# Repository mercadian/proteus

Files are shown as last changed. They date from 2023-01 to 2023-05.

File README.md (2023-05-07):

# Proteus

This repository contains the resources for creating and working with the Proteus.

*For documentation on setting up and using the Proteus, please see the **Wiki** tab above.*

*For the source code used to build the OS image that the Proteus comes with: please see the [proteus-image](https://github.com/mercadian/proteus-image) repository.*

## Contents

**labels** - contains `lumi` files for the model / serial number label on the bottom of the Proteus and the danger label attached to the power supply cable. Use the [Desktop Supplies editor](https://designer.desktopsupplies.com/?page_id=16&product_base=57&product_cms=127) to work with them, item template 62015.

**models** - contains the STL files used to print the Proteus case components.

**pcbs** - contains complete [KiCAD](https://www.kicad.org/) projects for supplemental PCBs used by the Proteus (for example, the front panel). Use KiCAD v6.0.11+.

**vanity-plate** - contains instructions and a sample for creating an image used to etch the Proteus's front aluminum vanity plate and other samples that have been made available for public consumption by generous customers.

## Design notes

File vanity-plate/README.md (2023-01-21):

# Proteus Vanity Plate

The vanity plate for the Proteus is an aluminum plate that can be laser etched with any image you like.

The plate itself is an 80mm x 30mm x 0.8mm flat sheet of aluminum, anodized black on both sides.
Supported images must be at most 76mm x 26mm because the engraver needs a 2mm margin per edge to etch safely. 

## Image Specifications

To create an image for the vanity plate, use the following rules.

- The image must be one of the following formats:
  - SVG, which must fit 76x26mm at 25px/mm
  - BMP, size 1900x650

- The colors must be **binary** (completely black or completely white only). The laser cannot etch grayscale colors; it's either on or off.
  - Grayscale pixels will be converted to black or white based on which color is closer, so please ensure the image you provide only uses black and white so you know what it will look like when it comes out.

- Use **black** for **unetched** background pixels, which will remain black on the actual plate. Use **white** for **foreground** pixels that will be etched; they will be a silvery-gold color on the actual plate.

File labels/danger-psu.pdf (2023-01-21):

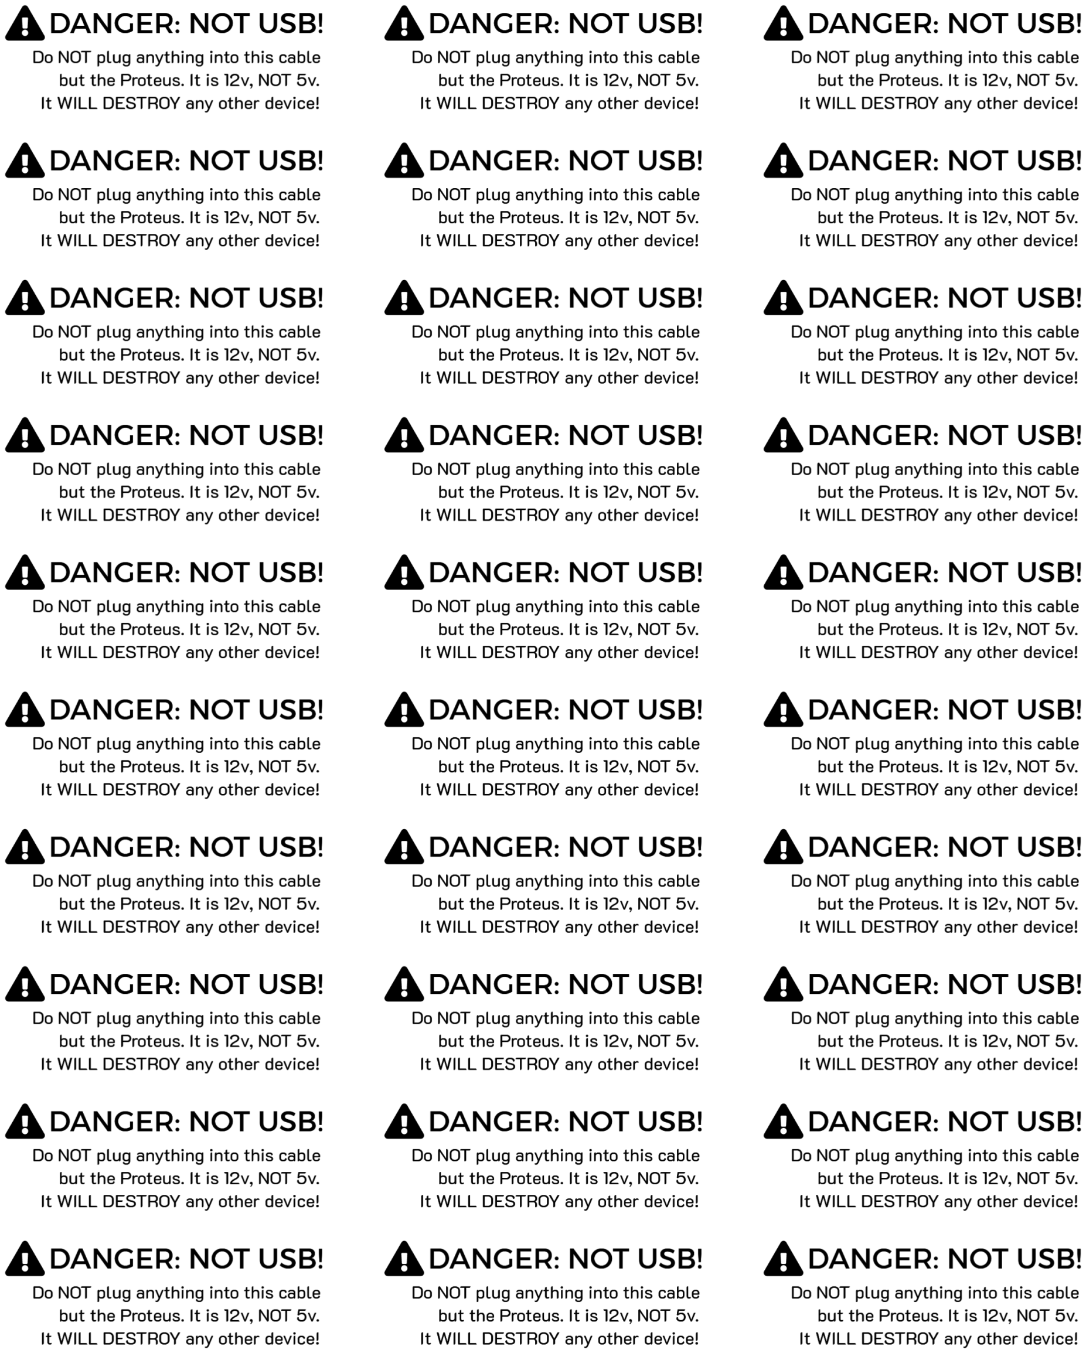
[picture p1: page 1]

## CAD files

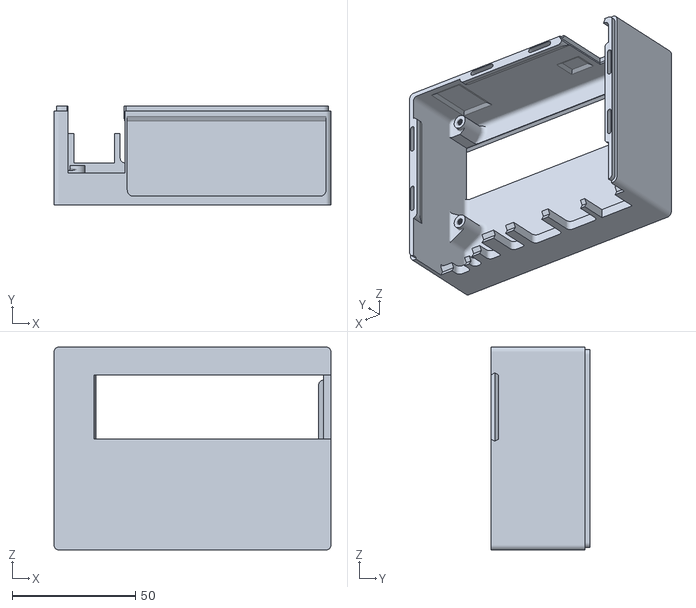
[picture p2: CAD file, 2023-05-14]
models/v1.1/case-bottom.stl
112.2 x 40.0 x 82.2

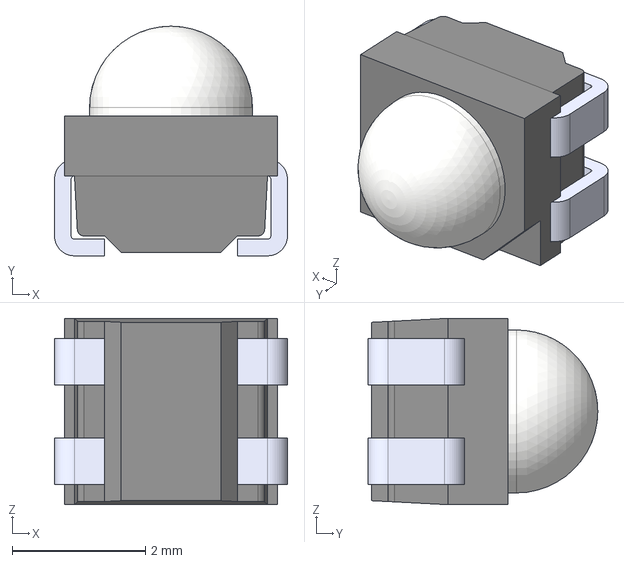
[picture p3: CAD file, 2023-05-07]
pcbs/front-panel/v1.2/models/CLM2D.STEP
3.50 x 3.45 x 2.80 mm

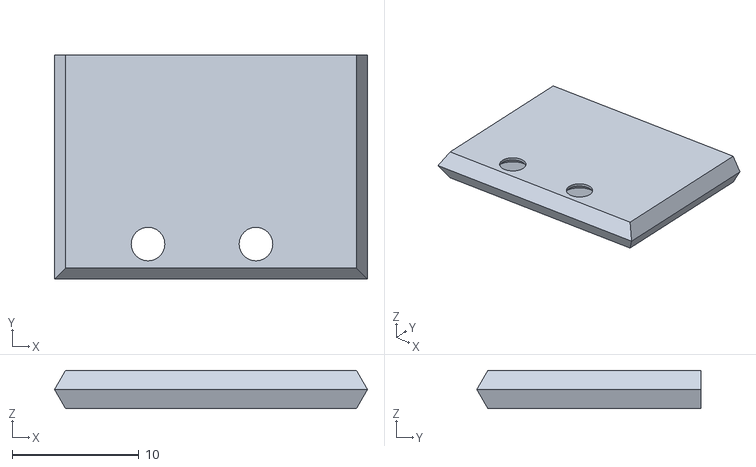
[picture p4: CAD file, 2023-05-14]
models/v1.1/front-panel.stl
24.7 x 17.7 x 3.00

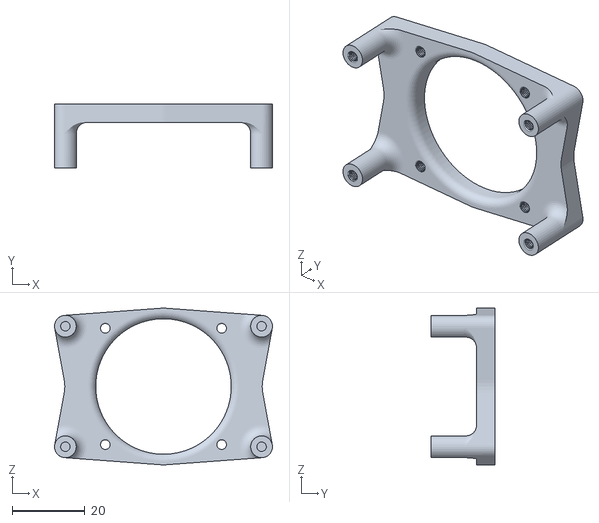
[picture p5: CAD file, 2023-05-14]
models/v1.1/fan-mount.stl
59.9 x 17.5 x 43.1

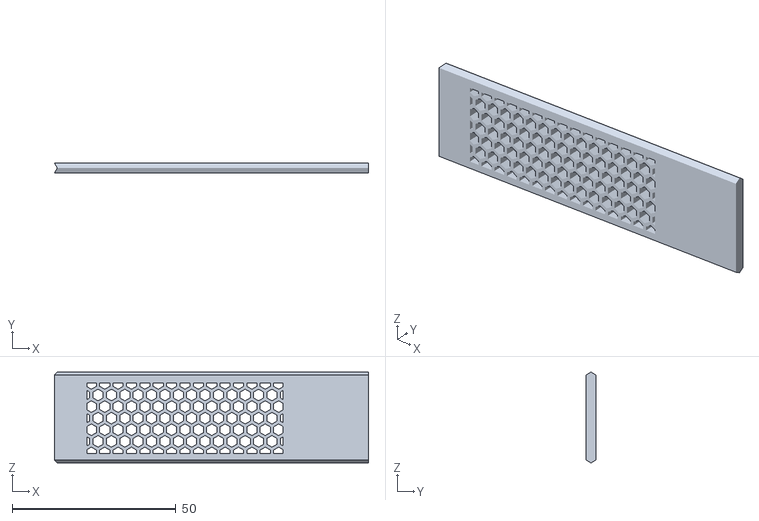
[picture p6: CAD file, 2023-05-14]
models/v1.1/ssd-cover.stl
96.0 x 3.00 x 27.8

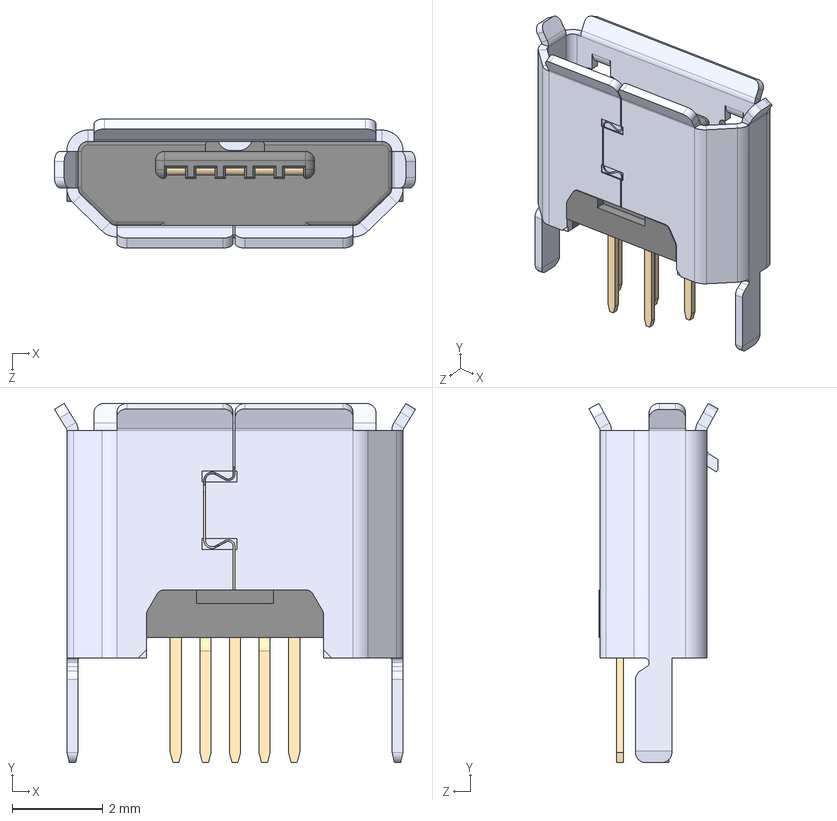
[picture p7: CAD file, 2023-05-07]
pcbs/gpio-board/v1.2/Models/USB3131-30-0230-A_REVB.step
7.94 x 7.90 x 2.84 mm

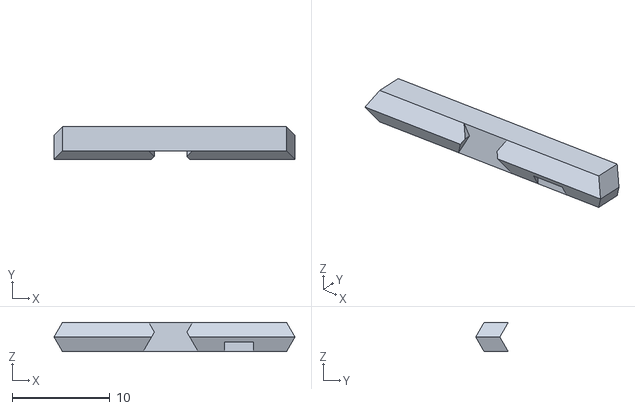
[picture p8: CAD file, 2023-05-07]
models/v1.1/power-button-holder-top.stl
24.7 x 3.34 x 3.00

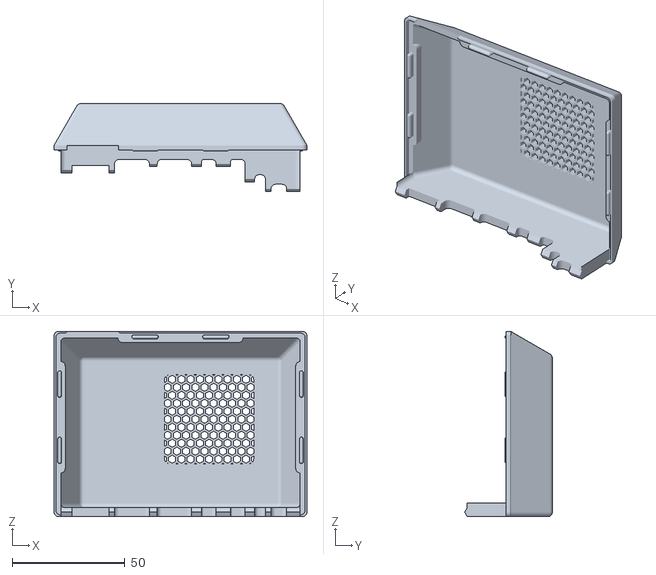
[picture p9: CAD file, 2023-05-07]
models/v1.1/case-top.stl
112.2 x 38.9 x 82.2

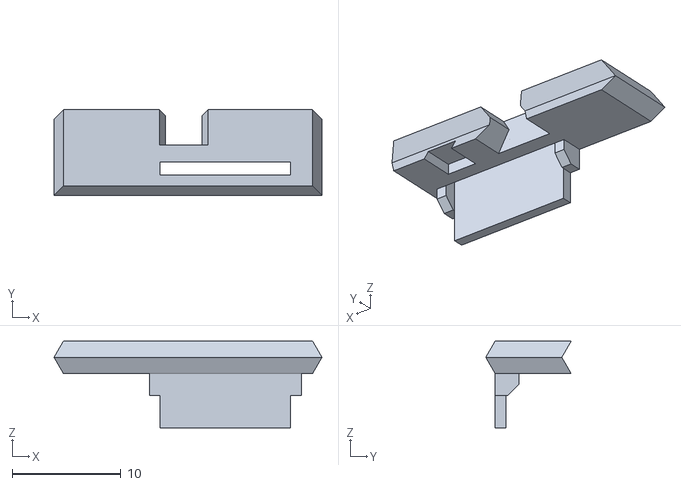
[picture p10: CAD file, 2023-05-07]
models/v1.1/power-button-holder-bottom.stl
24.7 x 7.87 x 8.00

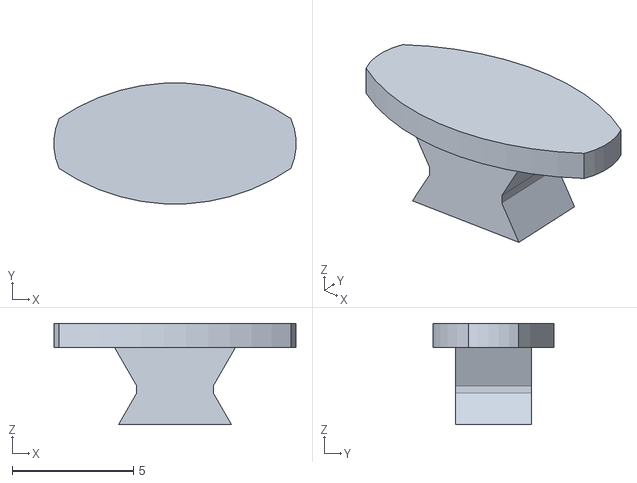
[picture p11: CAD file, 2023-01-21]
models/v1.1/power-button.stl
9.98 x 4.97 x 4.17

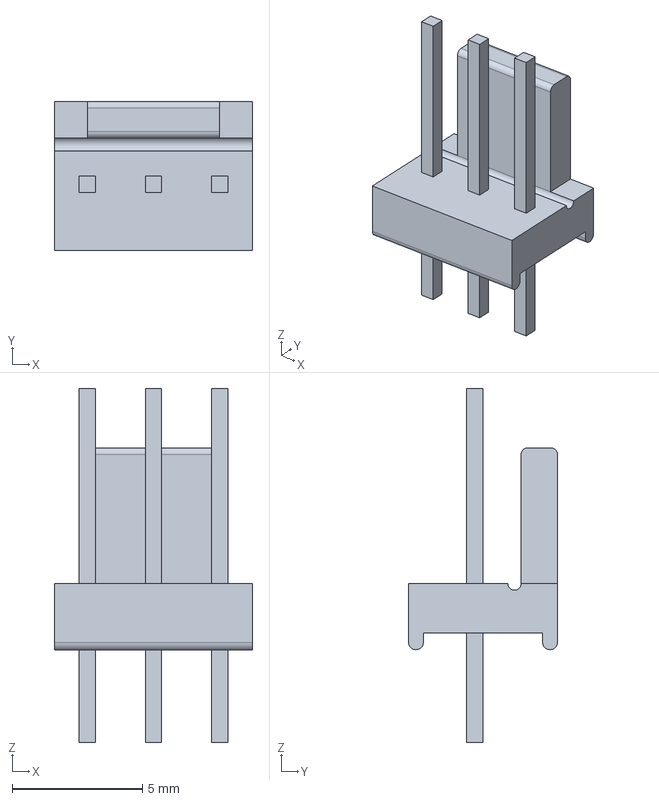
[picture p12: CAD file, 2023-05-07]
pcbs/front-panel/v1.2/step/640454-3.step
7.62 x 5.72 x 13.6 mm

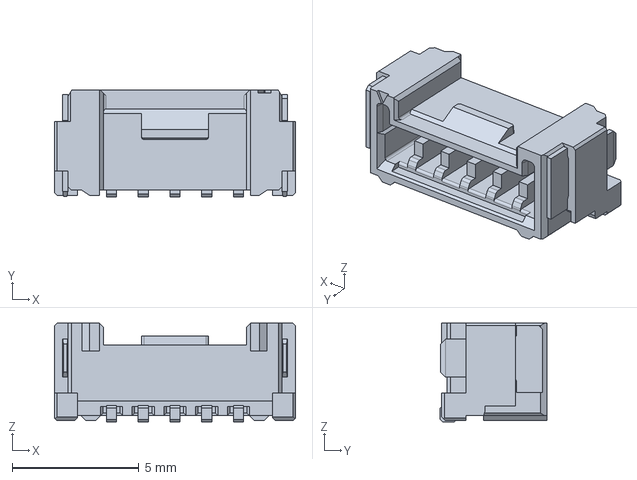
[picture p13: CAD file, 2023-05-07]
pcbs/gpio-board/v1.2/Models/5055680571.step
9.50 x 4.20 x 3.90 mm

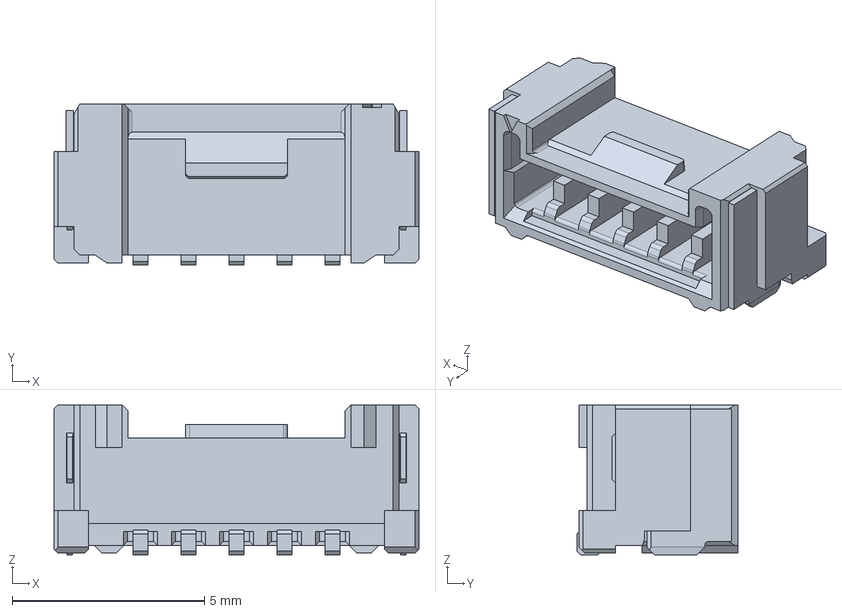
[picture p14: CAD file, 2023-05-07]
pcbs/front-panel/v1.2/models/5055670571.step
9.50 x 4.20 x 3.90 mm

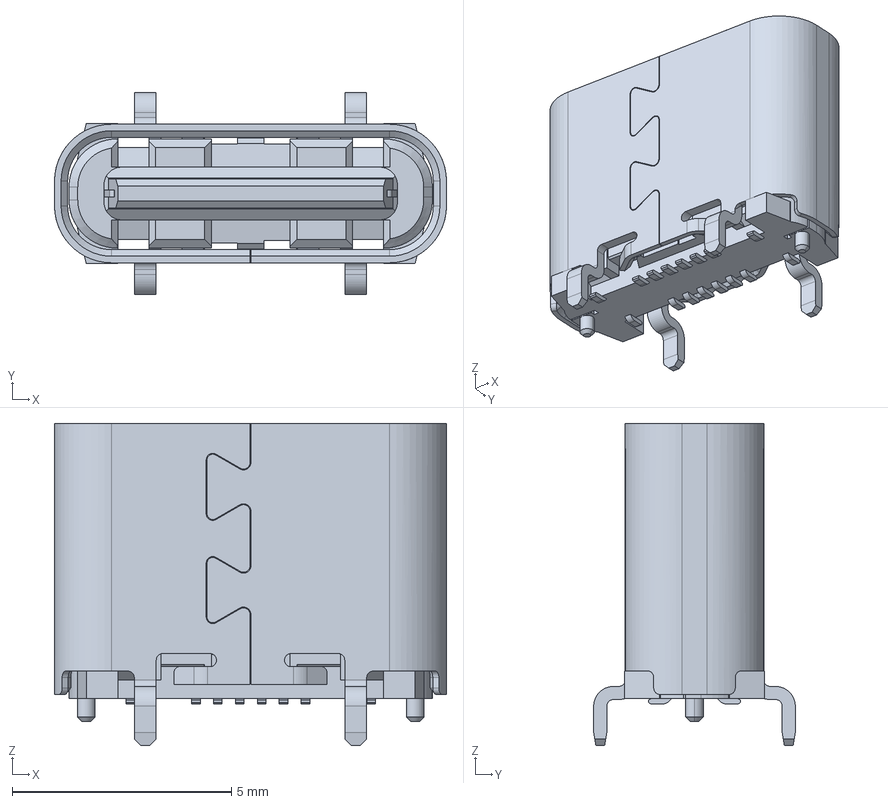
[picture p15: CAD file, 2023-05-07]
pcbs/gpio-board/v1.2/Models/2171820001.stp
8.94 x 4.60 x 7.35 mm

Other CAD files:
pcbs/gpio-board/v1.2/Models/61301621821.step
models/v1.0/power-button-holder-bottom.stl
models/v1.0/power-button-holder-top.stl
models/v1.0/case-bottom.stl
models/v1.0/case-top.stl
models/v1.0/fan-mount.stl
models/v1.0/front-panel.stl

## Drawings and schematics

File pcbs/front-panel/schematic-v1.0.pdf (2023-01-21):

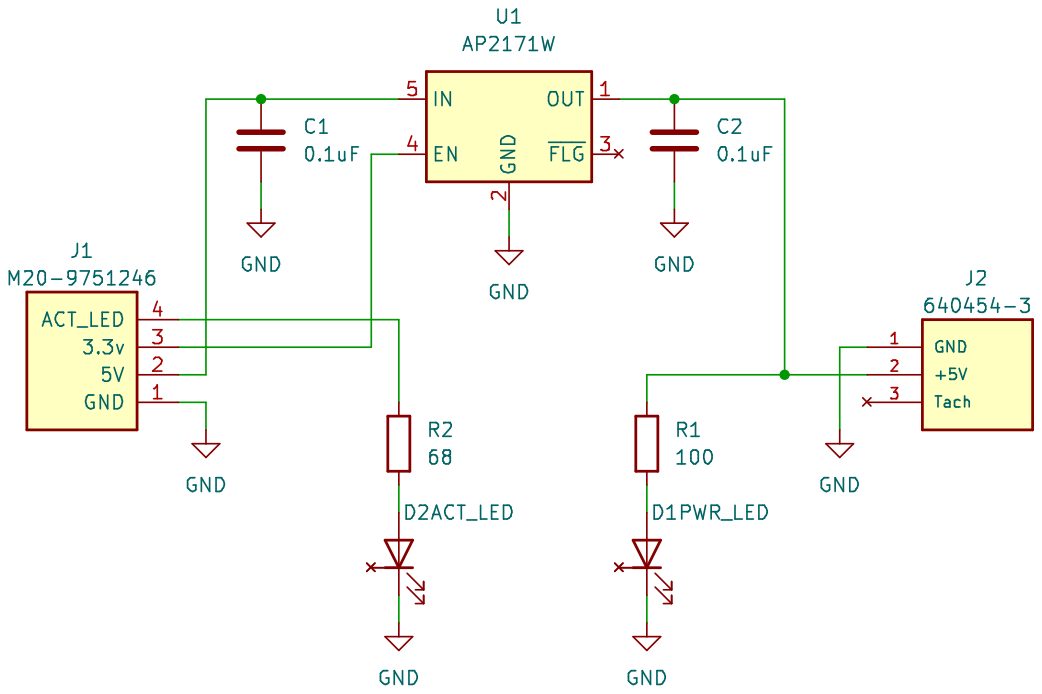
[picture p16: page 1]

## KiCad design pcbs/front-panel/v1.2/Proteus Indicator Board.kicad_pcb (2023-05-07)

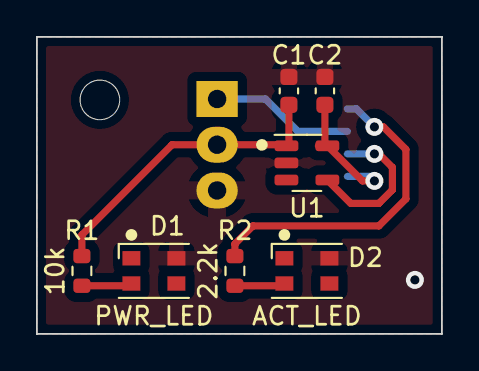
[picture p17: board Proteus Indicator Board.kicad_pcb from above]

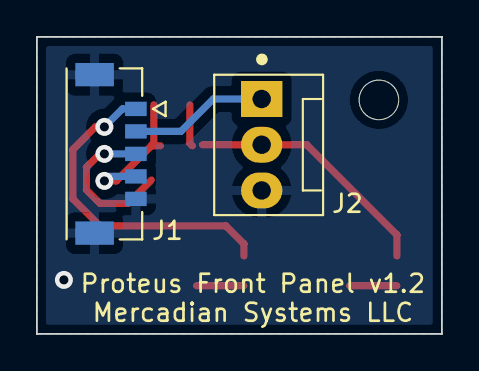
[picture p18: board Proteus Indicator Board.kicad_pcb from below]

Board: 2 copper layers, 22.5 x 16.5 mm, 9 parts (2 on the bottom side), 8 nets.

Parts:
C1, C2: 0.1uF; C_0603_1608Metric
D1: PWR_LED; LED_Cree-PLCC4_3.2x2.8mm_CCW
D2: ACT_LED; LED_Cree-PLCC4_3.2x2.8mm_CCW
J1: 5055670571; MOLEX_5055670571
J2: 640454-3; FanPinHeader_1x03_P2.54mm_Vertical
R1: 10k; R_0603_1608Metric
R2: 2.2k; R_0603_1608Metric
U1: AP2171W; SOT-23-5

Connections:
/3.3v: J1.3 (3.3v), U1.4 (EN)
/5v: C1.1, J2.2 (+5V), R1.1, U1.1 (OUT)
/5v_IN: C2.1, J1.4 (5v), U1.5 (IN)
/ACT_LED: J1.1 (Activity), R2.1
/Fan_Tach: J1.2 (Fan_Tach), J2.1 (Tach)
Earth: C1.2, C2.2, D1.1 (K), D2.1 (K), J1.5 (GND), J1.S1, J1.S2, J2.3 (GND), U1.2 (GND)
unnamed: D1.2 (A), R1.2
unnamed: D2.2 (A), R2.2

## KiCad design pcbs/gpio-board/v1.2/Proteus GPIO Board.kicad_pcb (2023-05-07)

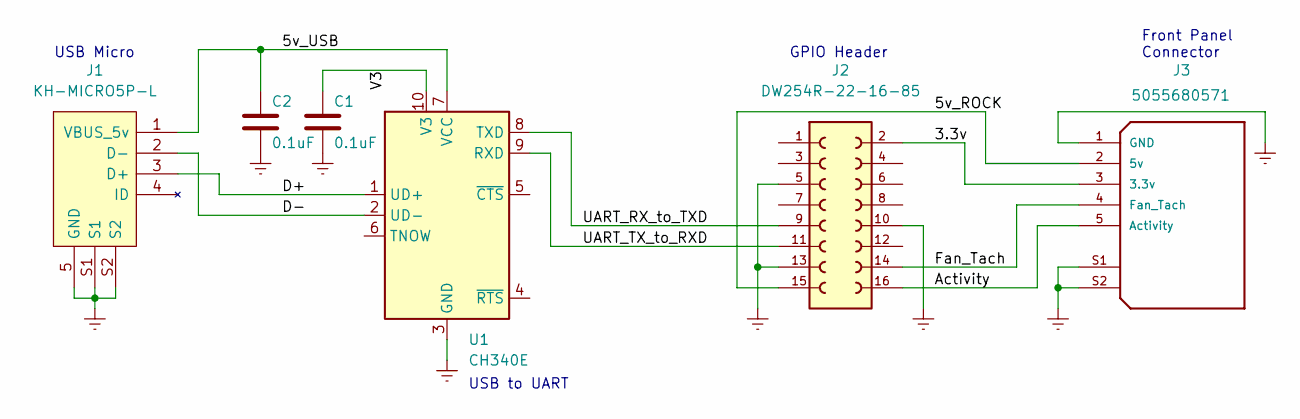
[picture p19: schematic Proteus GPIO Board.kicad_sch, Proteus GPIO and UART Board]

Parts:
C1, C2: 0.1uF; C_0603_1608Metric
J1: KH-MICRO5P-L; GCT_USB3131-30-0230-A_REVB; JLC C962220
J2: DW254R-22-16-85; 61301621821; JLC C2935989
J3: 5055680571; MOLEX_5055680571; PARTREV C; JLC C585386
U1: CH340E; MSOP-10_3x3mm_P0.5mm; JLC C99652

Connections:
/3.3v: J2.2, J3.3 (3.3v)
/5v_ROCK: J2.15, J3.2 (5v)
/5v_USB: C2.1, J1.1 (VBUS_5v), U1.7 (VCC)
/Activity: J2.16, J3.5 (Activity)
/D+: J1.3 (D+), U1.1 (UD+)
/D-: J1.2 (D-), U1.2 (UD-)
/Fan_Tach: J2.14, J3.4 (Fan_Tach)
/UART_RX_to_TXD: J2.9, U1.8 (TXD)
/UART_TX_to_RXD: J2.11, U1.9 (RXD)
/V3: C1.1, U1.10 (V3)
Earth: C1.2, C2.2, J1.5 (GND), J1.S1, J1.S2, J2.5, J2.10, J2.13, J3.1 (GND), J3.S1, J3.S2, U1.3 (GND)

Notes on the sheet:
GPIO Header
USB to UART
USB Micro
Front Panel Connector

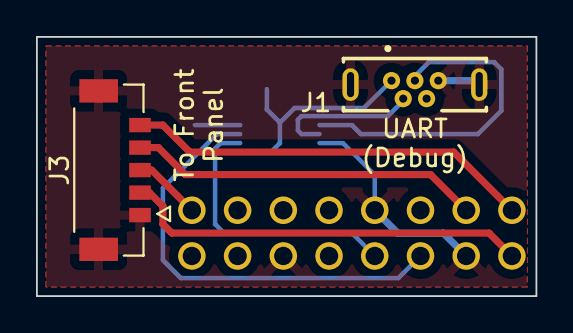
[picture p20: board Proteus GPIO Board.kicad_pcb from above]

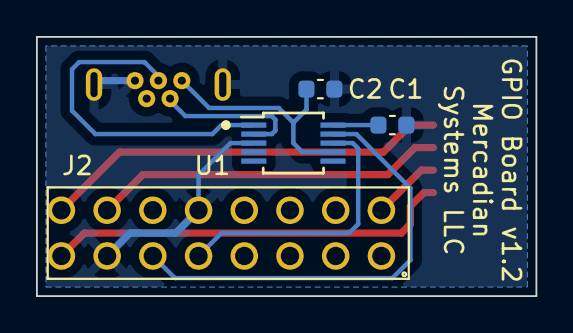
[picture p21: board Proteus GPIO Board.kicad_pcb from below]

Board: 2 copper layers, 27.8 x 14.4 mm, 6 parts (4 on the bottom side), 11 nets.

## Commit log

2023-01-21 Initial artifact commit
    [case-bottom.stl, case-top.stl, fan-mount.stl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]
2023-05-07 Added v1.1 and v1.2 artifacts
    [2171820001.stp, 5055670571.step, 5055680571.step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]
2023-05-14 Updated models for the new printer
    [case-bottom.stl, fan-mount.stl, front-panel.stl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]
2023-05-14 Added Fusion project for the v1.1 case

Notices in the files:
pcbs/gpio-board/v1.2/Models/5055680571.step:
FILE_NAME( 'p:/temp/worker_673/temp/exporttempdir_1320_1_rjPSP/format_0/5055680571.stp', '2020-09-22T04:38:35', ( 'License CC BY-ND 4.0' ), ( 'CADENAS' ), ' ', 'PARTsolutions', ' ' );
